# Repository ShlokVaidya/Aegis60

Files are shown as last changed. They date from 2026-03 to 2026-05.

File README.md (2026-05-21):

# Aegis60
Aegis60 is my custom 60% mechanical keyboard project built around an RP2040-ZERO controller.
<p>
I wanted a keyboard that felt clean and simple like a classic 60%, but still let me fully understand how the electronics actually work (matrix, diodes, routing, and firmware pin mapping), not just buy a kit and screw it together.
</p>
<br>


<br>
## Why I made this

I am 17 and I use my keyboard for school every day, so I wanted to build one that is actually mine from scratch.

Main goals I set for myself:
- Design a full 60% PCB in KiCad (61 keys)
- Use hot-swap MX footprints so it is easy to test switches
- Keep the design manufacturable and not just a concept render
- Learn the full pipeline: schematic -> PCB -> 3D model -> production files

## Project status

This repo includes the complete hardware design files and manufacturing outputs:
- KiCad project, schematic, and PCB
- 3D CAD export (.step)
- Plate DXF
- Production files (BOM, positions, designators, netlist)
- Custom RP2040-ZERO symbol/footprint library files

Current hardware summary:
- Layout: 60% ANSI style, 61 keys
- Controller: RP2040-ZERO
- Matrix: diode matrix (1 diode per switch)
- Stabilizers: 2u, 2.25u, 2.75u, 6.25u support

## Images

### Full 3D model screenshot

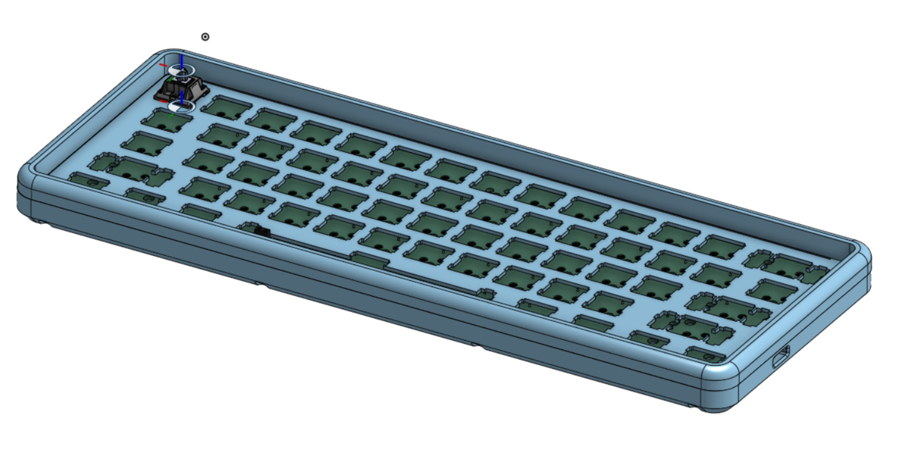
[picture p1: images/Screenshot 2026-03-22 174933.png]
Aegis60 full 3D model


### PCB screenshot

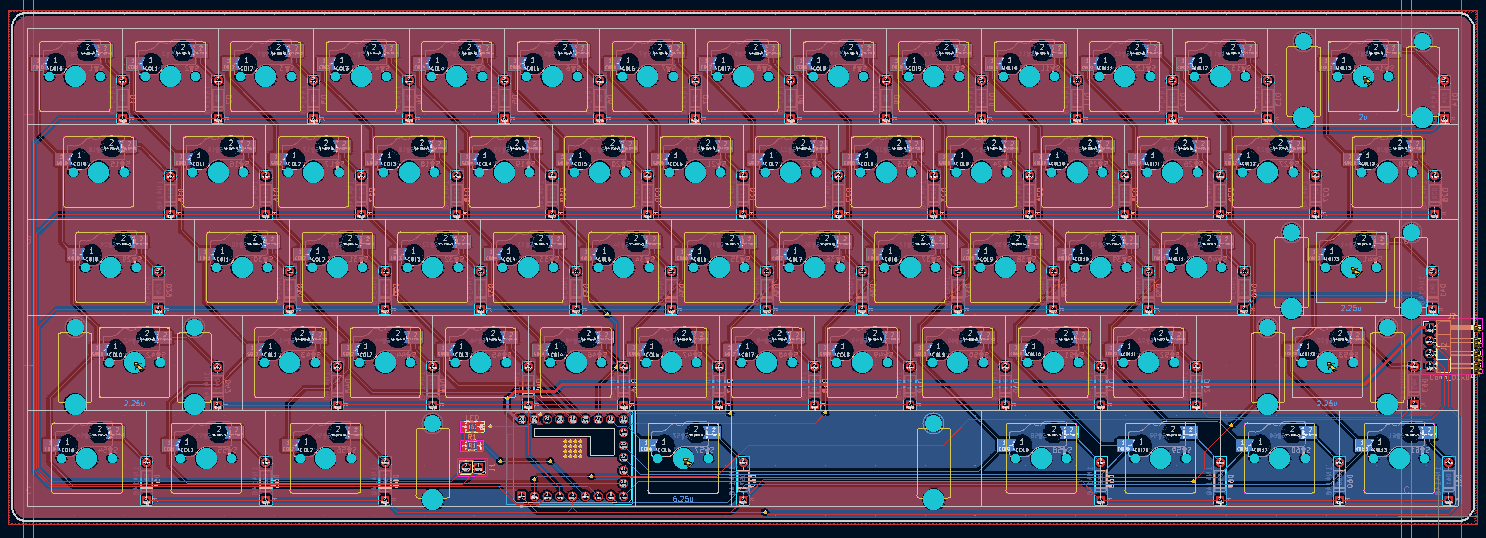
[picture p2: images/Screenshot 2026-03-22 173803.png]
Aegis60 PCB routing


### Wiring / schematic screenshot

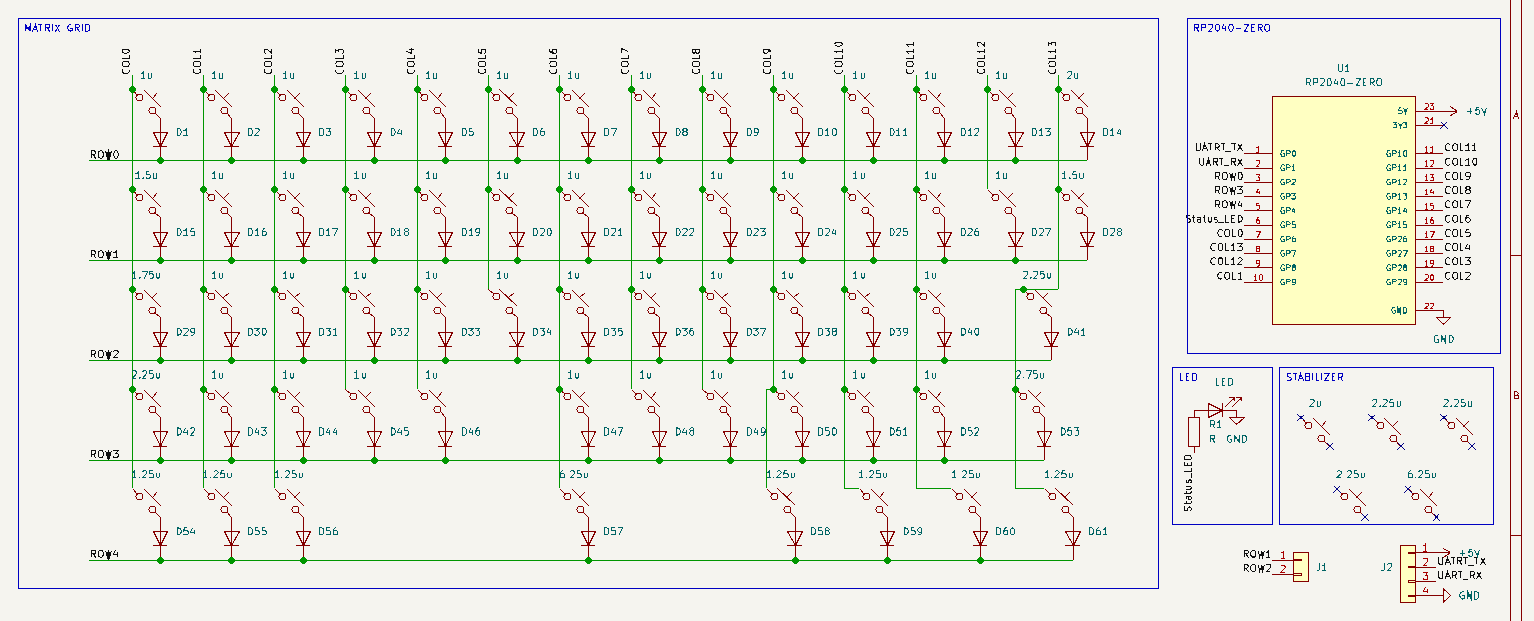
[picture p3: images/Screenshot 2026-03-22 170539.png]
Aegis60 schematic matrix and RP2040 pinout


### Other Screenshots













### Build







## Repo file checklist

Important files in this repository:
- `Aegis60.kicad_pro`
- `Aegis60.kicad_sch`
- `Aegis60.kicad_pcb`
- `Aegis60.step`
- `Plate.dxf`
- `bom.csv`
- `production/bom.csv`
- `production/positions.csv`
- `production/designators.csv`
- `production/netlist.ipc`

## CAD

OnShape: [link](https://cad.onshape.com/documents/3631dcb843d220359551c32b/w/64ccd39e08fb4eede3b1f39f/e/fad0ee0c4f93314d35213121)

## Firmware note

A KMK starter firmware is included in this repo:

- `firmware/kmk/main.py`
- `firmware/kmk/README.md`

It includes the row/column pin mapping from the current netlist and a base ANSI-like 61-key layout.

## BOM (summary)

Current BOM is in `bom.csv`.

| Name | Purpose | Quantity | Total Cost (USD) | Distributor | Link |
|---|---|---:|---:|---|---|
| 3D printed Case | 3D printing | 1 | 8.19 | Hack Club | https://printlegion.hackclub.com |
| PCB fabrication | PCB | 1 | 39.20 | Robu.in | https://robu.in/product/online-pcb-manufacturing-service/ |
| RP2040-zero | Microcontroller | 1 | 6.05 | Robu.in | https://robu.in/product/waveshare-rp2040-zero-raspberry-pi-mcu-with-presoldered-header/ |
| Cherry PBT Keycaps | Keycaps | 1 | 17.47 | Curiosity Caps | https://curiositycaps.in/products/counter-strike-printstream-decal-collectio-n-cherry-pbt-keycaps |
| Durock Smokey Screw-In Stabilizers V2 | Stabilizers | 1 | 17.00 | StacksKB | https://stackskb.com/store/durock-smokey-screw-in-stabilizers-v2/ |
| Akko V5 Creamy Blue Pro Switch (Pack of 45) | For typing I guess ? | 1 | 13.14 | StacksKB | https://stackskb.com/store/akko-v5-creamy-blue-pro-switch-pack-of-45/ |

**Total BOM cost:** 101.05 USD

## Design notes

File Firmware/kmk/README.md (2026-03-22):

# Aegis60 KMK Firmware

This is a starter KMK firmware for the Aegis60 (RP2040-ZERO).

## What this includes
- Exact row/column GPIO mapping from the current hardware netlist
- 61-key ANSI-like base layer
- Sparse matrix handling with `KC.NO` for physically empty matrix slots

## Flash steps
1. Install CircuitPython on RP2040-ZERO (if not already installed).
2. Copy the KMK library folder to your `CIRCUITPY` drive.
3. Copy `main.py` from this folder to the root of `CIRCUITPY`.
4. Replug/reset the board.

## Notes
- Matrix diode direction is configured as `COL2ROW`.
- In the schematic/netlist, GP0/GP1 are named `UATRT_TX` / `UART_RX` but are used as matrix rows in this design.
- If any key appears in the wrong place, verify switch orientation and matrix continuity first, then tune keycodes in `main.py`.

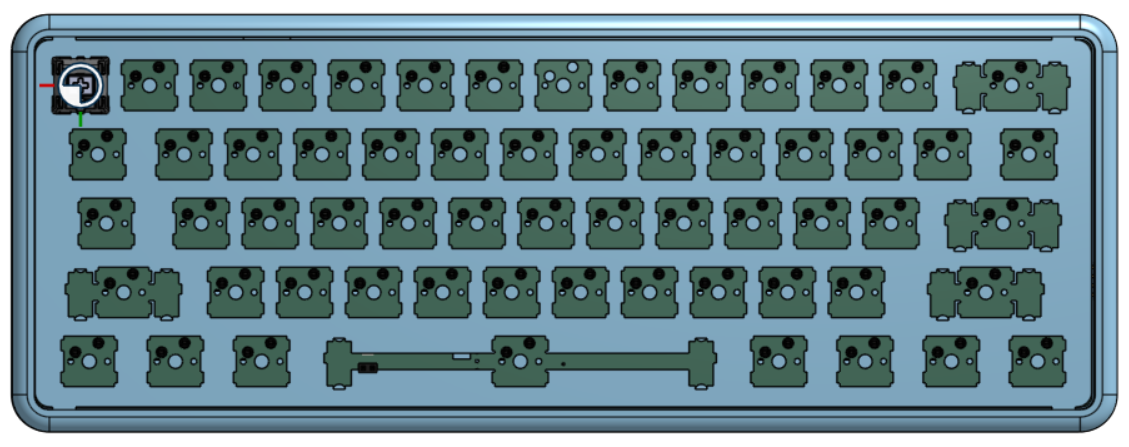
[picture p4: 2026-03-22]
images/Screenshot 2026-03-22 175005.png

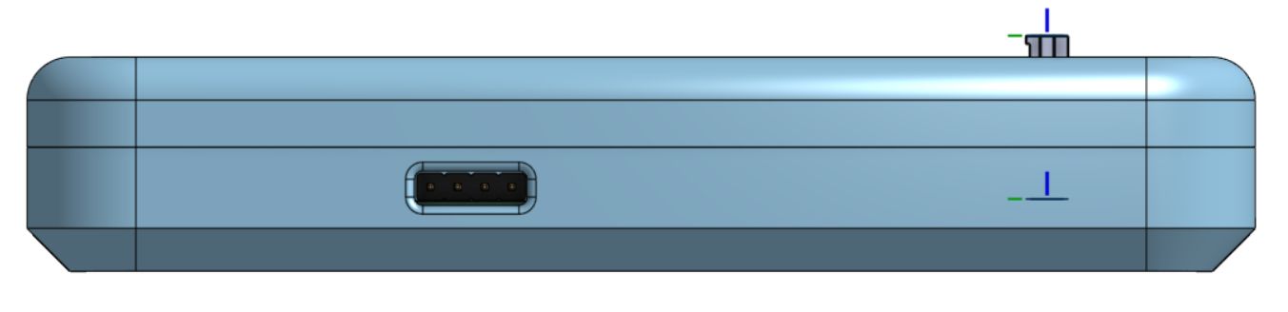
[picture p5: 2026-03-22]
images/Screenshot 2026-03-22 175134.png

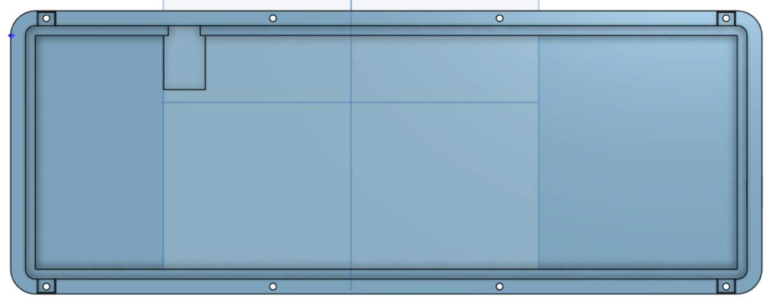
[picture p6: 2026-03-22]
images/Screenshot 2026-03-22 175245.png

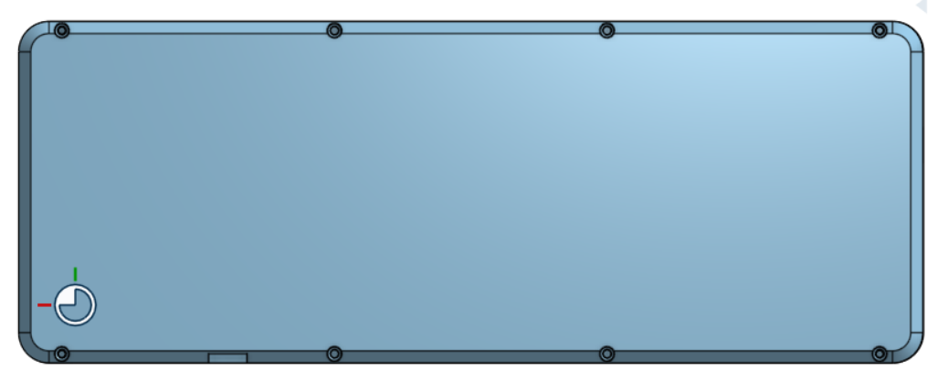
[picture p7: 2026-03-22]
images/Screenshot 2026-03-22 175213.png

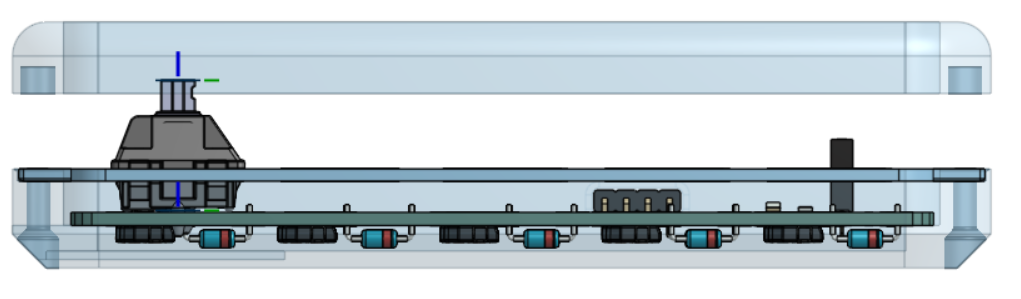
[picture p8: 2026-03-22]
images/Screenshot 2026-03-22 175058.png

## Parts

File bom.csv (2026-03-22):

Name | Purpose | Quantity | Total Cost (USD) | Link | Distributor
3D printed Case | 3D printing | 1 | 8.19 | https://printlegion.hackclub.com | Hack Club
PCB fabrication | PCB | 1 | 39.20 | https://robu.in/product/online-pcb-manufacturing-service/ | Robu.in
RP2040-zero | Microcontroller | 1 | 6.05 | https://robu.in/product/waveshare-rp2040-zero-raspberry-pi-mcu-with-presoldered-header/ | Robu.in
Cherry PBT Keycaps | Keycaps | 1 | 17.47 | https://curiositycaps.in/products/counter-strike-printstream-decal-collectio-n-cherry-pbt-keycaps | Curiosity Caps
Durock Smokey Screw-In Stabilizers V2 | Stabilizers | 1 | 17.00 | https://stackskb.com/store/durock-smokey-screw-in-stabilizers-v2/ | StacksKB
Akko V5 Creamy Blue Pro Switch (Pack of 45) | For typing I guess ? | 1 | 13.14 | https://stackskb.com/store/akko-v5-creamy-blue-pro-switch-pack-of-45/ | StacksKB

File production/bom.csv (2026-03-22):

Designator | Footprint | Quantity | Value | LCSC Part #
D1, D10, D11, D12, D13, D14, D15, D16, D17, D18, D19, D2, D20, D21, D22, D23, D24, D25, D26, D27, D28, D29, D3, D30, D31, D32, D33, D34, D35, D36, D37, D38, D39, D4, D40, D41, D42, D43, D44, D45, D46, D47, D48, D49, D5, D50, D51, D52, D53, D54, D55, D56, D57, D58, D59, D6, D60, D61, D7, D8, D9 | D_DO-35_SOD27_P7.62mm_Horizontal | 61 | 1N4148
D62 | 1206 | 1 | LED
J1 | PinSocket_1x02_P2.54mm_Vertical | 1 | Conn_01x02
J2 | PinHeader_1x04_P2.54mm_Horizontal | 1 | Conn_01x04
R1 | 1206 | 1 | R
STAB1 | STAB_MX_2u | 1 | 2u
STAB2, STAB3 | STAB_MX_2.25u | 2 | 2.25u
STAB4 | STAB_MX_2.75u | 1 | 2.25u
STAB5 | STAB_MX_6.25u | 1 | 6.25u
SW1, SW10, SW11, SW12, SW13, SW16, SW17, SW18, SW19, SW2, SW20, SW21, SW22, SW23, SW24, SW25, SW26, SW27, SW3, SW30, SW31, SW32, SW33, SW34, SW35, SW36, SW37, SW38, SW39, SW4, SW40, SW43, SW44, SW45, SW46, SW47, SW48, SW49, SW5, SW50, SW51, SW52, SW6, SW7, SW8, SW9 | SW_MX_HS_KS-2P02B01-01_1u | 46 | 1u
SW14 | SW_MX_HS_KS-2P02B01-01_1u | 1 | 2u
SW15, SW28 | SW_MX_HS_KS-2P02B01-01_1.5u | 2 | 1.5u
SW29 | SW_MX_HS_KS-2P02B01-01_1.75u | 1 | 1.75u
SW41, SW42 | SW_MX_HS_KS-2P02B01-01_1u | 2 | 2.25u
SW53 | SW_MX_HS_KS-2P02B01-01_1u | 1 | 2.75u
SW54, SW55, SW56, SW58, SW59, SW60, SW61 | SW_MX_HS_KS-2P02B01-01_1.25u | 7 | 1.25u
SW57 | SW_MX_HS_KS-2P02B01-01_1u | 1 | 6.25u
U1 | MODULE_RP2040-ZERO | 1 | RP2040-ZERO

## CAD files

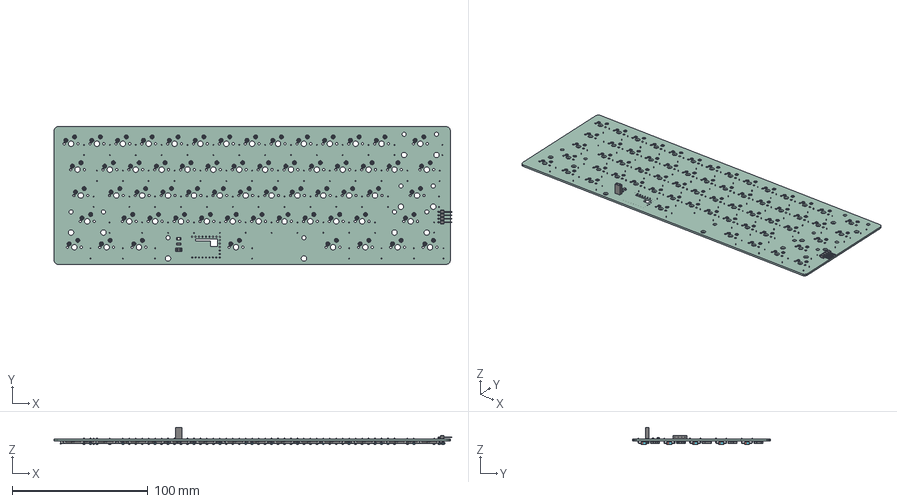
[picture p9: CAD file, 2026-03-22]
Aegis60.step
293.1 x 101.4 x 12.7 mm
PinSocket_1x02_P2.54mm_Vertical
R_1206_3216Metric
LED_1206_3216Metric
PinHeader_1x04_P2.54mm_Horizontal
HS_KS-2P02B01-01_MX x 61
D_DO-35_SOD27_P7.62mm_Horizontal x 61
Aegis60_PCB

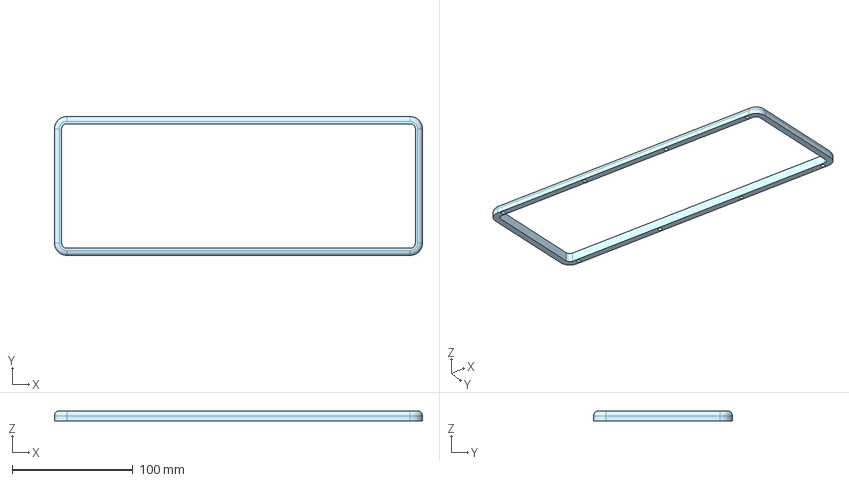
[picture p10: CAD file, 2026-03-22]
CAD/Cover.step
305.0 x 115.0 x 8.40 mm

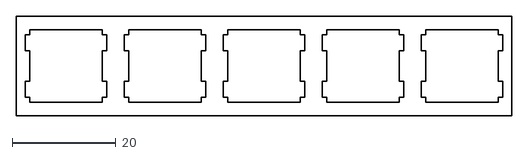
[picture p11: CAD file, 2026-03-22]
PCB/Plate.dxf
95.3 x 19.1

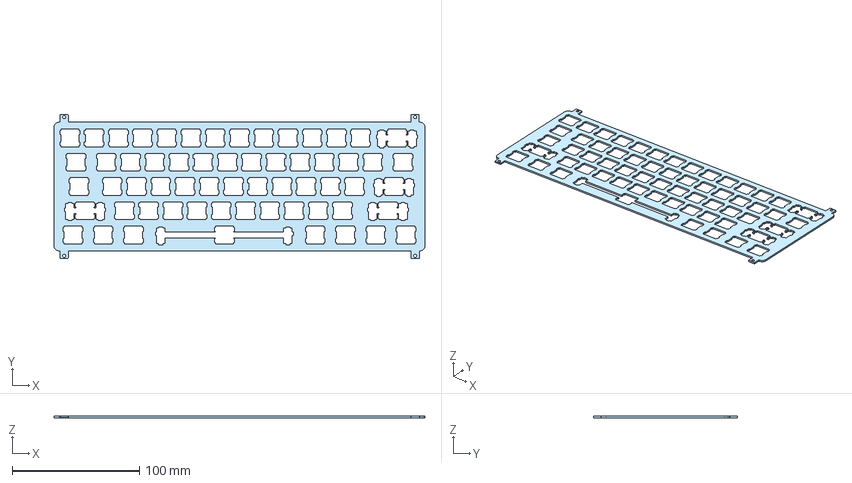
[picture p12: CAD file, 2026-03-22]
CAD/Plate.step
291.7 x 113.4 x 1.40 mm

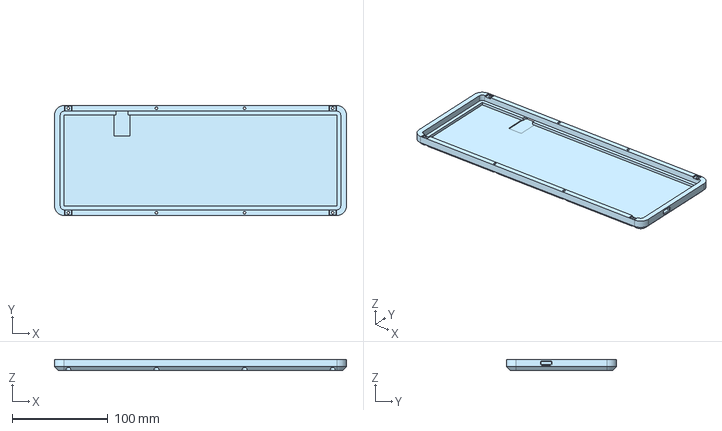
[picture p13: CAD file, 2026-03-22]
CAD/Bottom_Case.step
305.0 x 115.0 x 11.6 mm

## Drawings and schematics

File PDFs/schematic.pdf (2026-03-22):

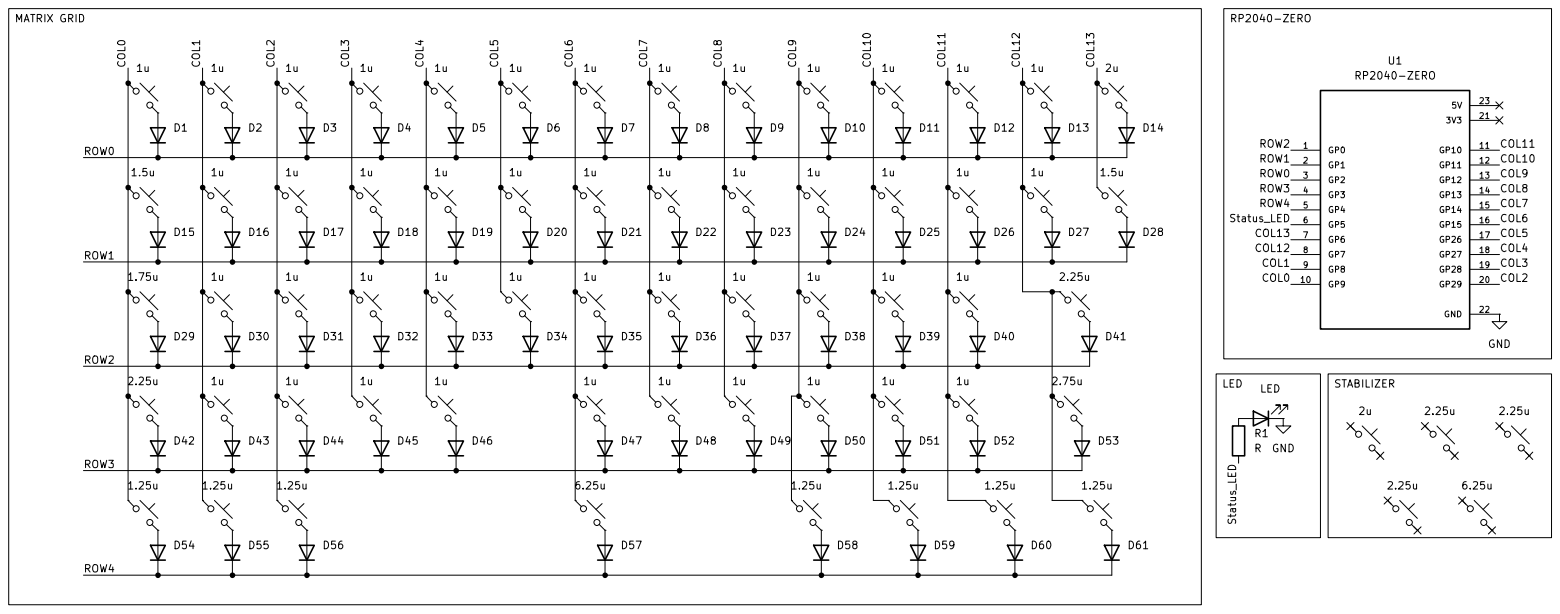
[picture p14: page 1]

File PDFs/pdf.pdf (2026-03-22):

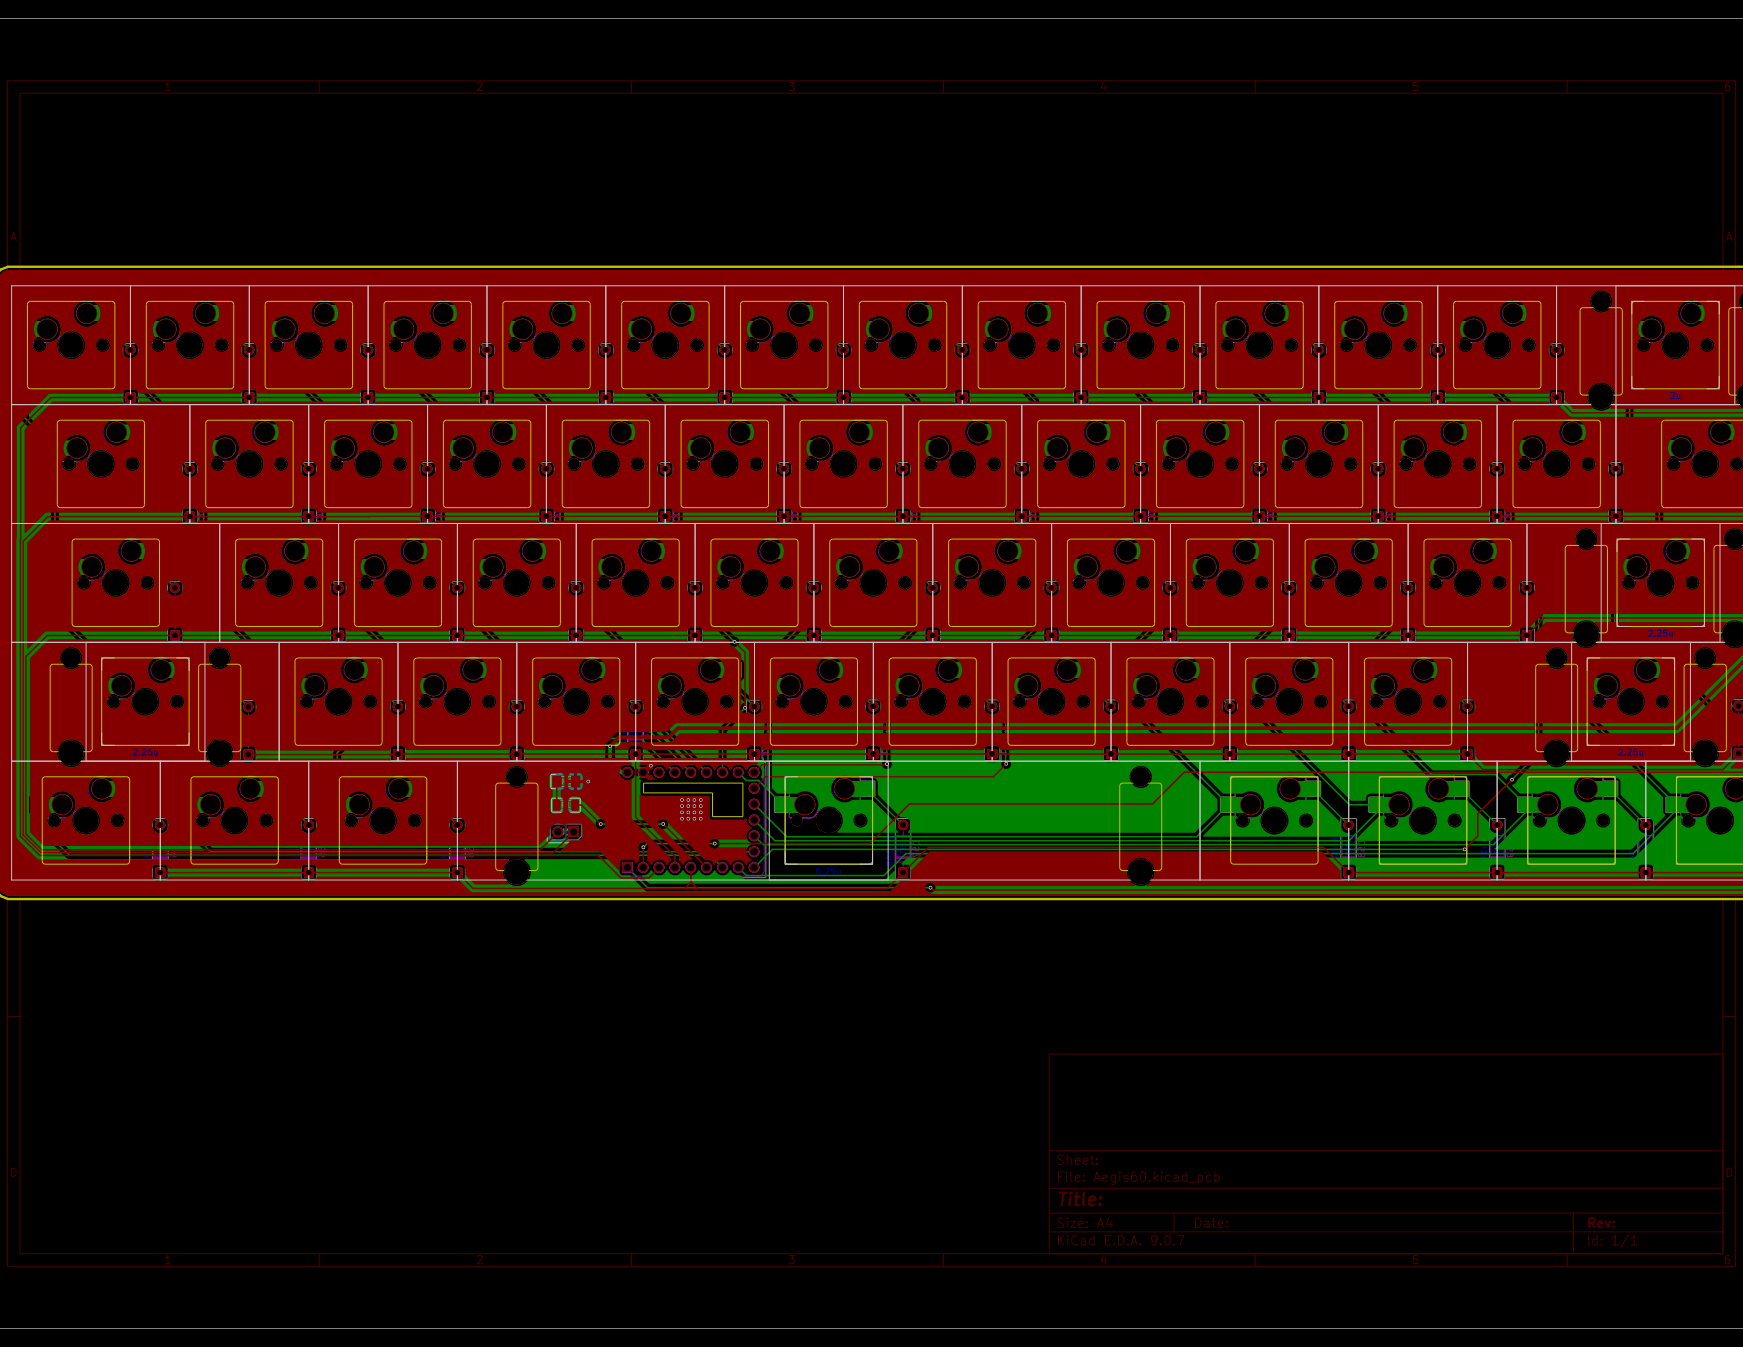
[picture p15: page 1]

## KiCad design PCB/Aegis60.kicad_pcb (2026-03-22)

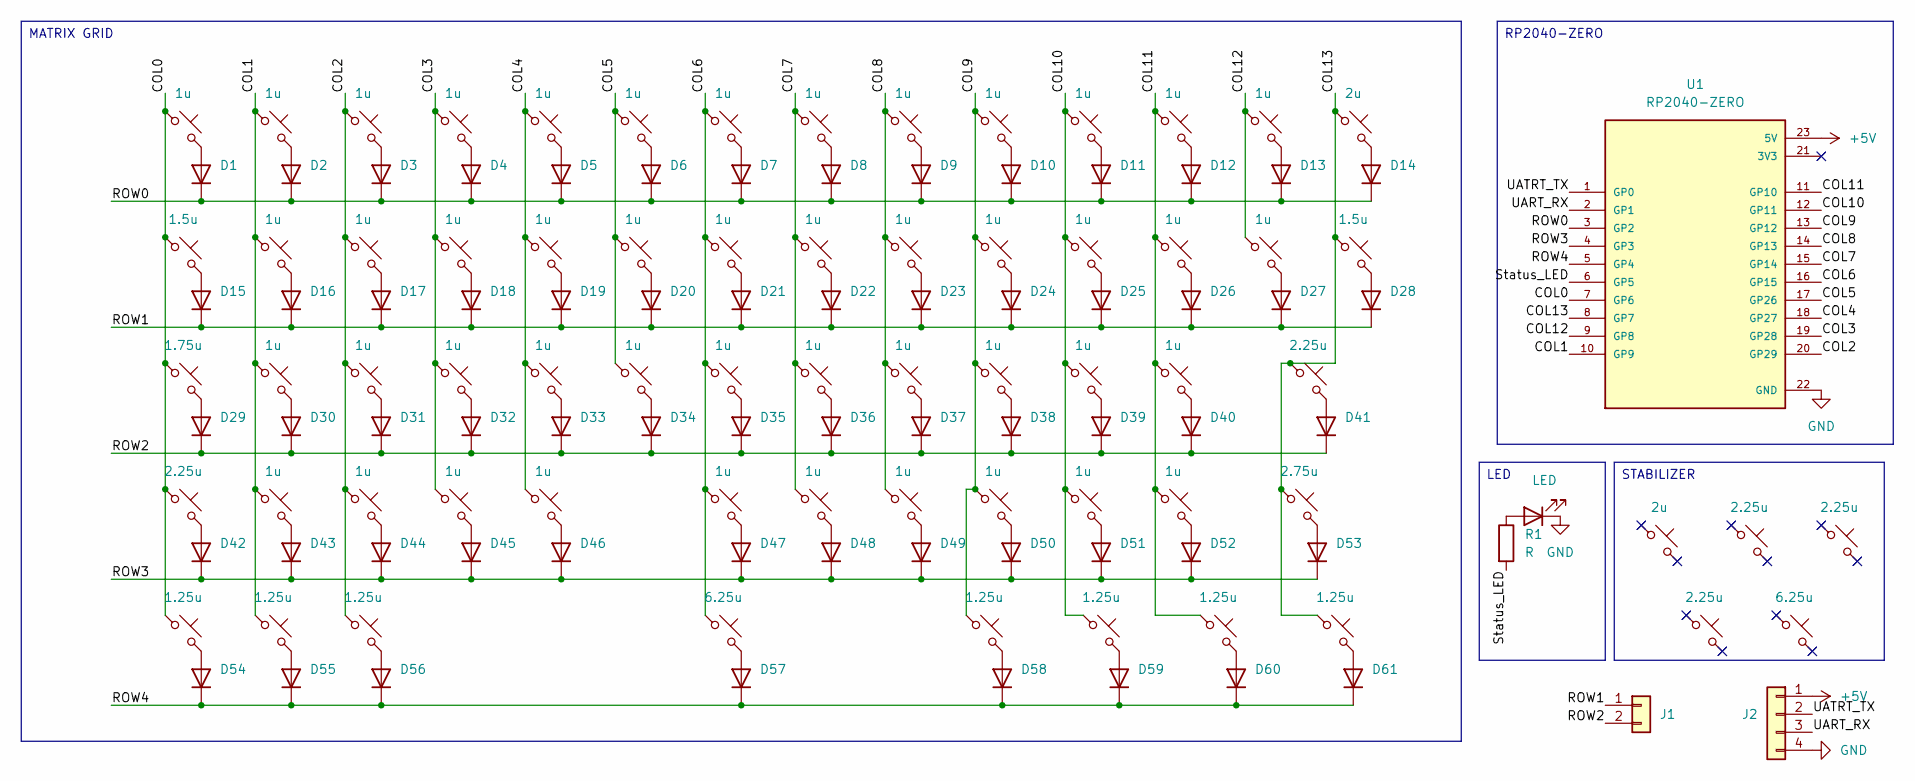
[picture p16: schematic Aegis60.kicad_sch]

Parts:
D1, D2, D3, D4, D5, D6, D7, D8, D9, D10, D11, D12, D13, D14, D15, D16, D17, D18, D19, D20, D21, D22, D23, D24, D25, D26, D27, D28, D29, D30, D31, D32, D33, D34, D35, D36, D37, D38, D39, D40, D41, D42, D43, D44, D45, D46, D47, D48, D49, D50, D51, D52, D53, D54, D55, D56, D57, D58, D59, D60, D61: 1N4148; D_DO-35_SOD27_P7.62mm_Horizontal
D62: LED; LED_1206_3216Metric_Pad1.42x1.75mm_HandSolder
J1: Conn_01x02; PinSocket_1x02_P2.54mm_Vertical
J2: Conn_01x04; PinHeader_1x04_P2.54mm_Horizontal
R1: R; R_1206_3216Metric
STAB1: 2u; STAB_MX_2u
STAB2, STAB3: 2.25u; STAB_MX_2.25u
STAB4: 2.25u; STAB_MX_2.75u
STAB5: 6.25u; STAB_MX_6.25u
SW1, SW2, SW3, SW4, SW5, SW6, SW7, SW8, SW9, SW10, SW11, SW12, SW13, SW16, SW17, SW18, SW19, SW20, SW21, SW22, SW23, SW24, SW25, SW26, SW27, SW30, SW31, SW32, SW33, SW34, SW35, SW36, SW37, SW38, SW39, SW40, SW43, SW44, SW45, SW46, SW47, SW48, SW49, SW50, SW51, SW52: 1u; SW_MX_HS_KS-2P02B01-01_1u
SW14: 2u; SW_MX_HS_KS-2P02B01-01_1u
SW15, SW28: 1.5u; SW_MX_HS_KS-2P02B01-01_1.5u
SW29: 1.75u; SW_MX_HS_KS-2P02B01-01_1.75u
SW41, SW42: 2.25u; SW_MX_HS_KS-2P02B01-01_1u
SW53: 2.75u; SW_MX_HS_KS-2P02B01-01_1u
SW54, SW55, SW56, SW58, SW59, SW60, SW61: 1.25u; SW_MX_HS_KS-2P02B01-01_1.25u
SW57: 6.25u; SW_MX_HS_KS-2P02B01-01_1u
U1: RP2040-ZERO; MODULE_RP2040-ZERO; PARTREV NA

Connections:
+5V: J2.1, U1.23 (5V)
/COL0: SW1.1, SW15.1, SW29.1, SW42.1, SW54.1, U1.7 (GP6)
/COL1: SW2.1, SW16.1, SW30.1, SW43.1, SW55.1, U1.10 (GP9)
/COL2: SW3.1, SW17.1, SW31.1, SW44.1, SW56.1, U1.20 (GP29)
/COL3: SW4.1, SW18.1, SW32.1, SW45.1, U1.19 (GP28)
/COL4: SW5.1, SW19.1, SW33.1, SW46.1, U1.18 (GP27)
/COL5: SW6.1, SW20.1, SW34.1, U1.17 (GP26)
/COL6: SW7.1, SW21.1, SW35.1, SW47.1, SW57.1, U1.16 (GP15)
/COL7: SW8.1, SW22.1, SW36.1, SW48.1, U1.15 (GP14)
/COL8: SW9.1, SW23.1, SW37.1, SW49.1, U1.14 (GP13)
/COL9: SW10.1, SW24.1, SW38.1, SW50.1, SW58.1, U1.13 (GP12)
/COL10: SW11.1, SW25.1, SW39.1, SW51.1, SW59.1, U1.12 (GP11)
/COL11: SW12.1, SW26.1, SW40.1, SW52.1, SW60.1, U1.11 (GP10)
/COL12: SW13.1, SW27.1, U1.9 (GP8)
/COL13: SW14.1, SW28.1, SW41.1, SW53.1, SW61.1, U1.8 (GP7)
/ROW0: D1.1 (K), D2.1 (K), D3.1 (K), D4.1 (K), D5.1 (K), D6.1 (K), D7.1 (K), D8.1 (K), D9.1 (K), D10.1 (K), D11.1 (K), D12.1 (K), D13.1 (K), D14.1 (K), U1.3 (GP2)
/ROW1: D15.1 (K), D16.1 (K), D17.1 (K), D18.1 (K), D19.1 (K), D20.1 (K), D21.1 (K), D22.1 (K), D23.1 (K), D24.1 (K), D25.1 (K), D26.1 (K), D27.1 (K), D28.1 (K), J1.1
/ROW2: D29.1 (K), D30.1 (K), D31.1 (K), D32.1 (K), D33.1 (K), D34.1 (K), D35.1 (K), D36.1 (K), D37.1 (K), D38.1 (K), D39.1 (K), D40.1 (K), D41.1 (K), J1.2
/ROW3: D42.1 (K), D43.1 (K), D44.1 (K), D45.1 (K), D46.1 (K), D47.1 (K), D48.1 (K), D49.1 (K), D50.1 (K), D51.1 (K), D52.1 (K), D53.1 (K), U1.4 (GP3)
/ROW4: D54.1 (K), D55.1 (K), D56.1 (K), D57.1 (K), D58.1 (K), D59.1 (K), D60.1 (K), D61.1 (K), U1.5 (GP4)
/Status_LED: R1.2, U1.6 (GP5)
/UART_RX: J2.3, U1.2 (GP1)
/UATRT_TX: J2.2, U1.1 (GP0)
GND: D62.1 (K), J2.4, U1.22 (GND)
unnamed: D1.2 (A), SW1.2
unnamed: D2.2 (A), SW2.2
unnamed: D3.2 (A), SW3.2
unnamed: D4.2 (A), SW4.2
unnamed: D5.2 (A), SW5.2
unnamed: D6.2 (A), SW6.2
unnamed: D7.2 (A), SW7.2
unnamed: D8.2 (A), SW8.2
unnamed: D9.2 (A), SW9.2
unnamed: D10.2 (A), SW10.2
unnamed: D11.2 (A), SW11.2
unnamed: D12.2 (A), SW12.2
unnamed: D13.2 (A), SW13.2
unnamed: D14.2 (A), SW14.2
unnamed: D15.2 (A), SW15.2
unnamed: D16.2 (A), SW16.2
unnamed: D17.2 (A), SW17.2
unnamed: D18.2 (A), SW18.2
unnamed: D19.2 (A), SW19.2
unnamed: D20.2 (A), SW20.2
unnamed: D21.2 (A), SW21.2
unnamed: D22.2 (A), SW22.2
unnamed: D23.2 (A), SW23.2
unnamed: D24.2 (A), SW24.2
unnamed: D25.2 (A), SW25.2
unnamed: D26.2 (A), SW26.2
unnamed: D27.2 (A), SW27.2
unnamed: D28.2 (A), SW28.2
unnamed: D29.2 (A), SW29.2
unnamed: D30.2 (A), SW30.2
unnamed: D31.2 (A), SW31.2
unnamed: D32.2 (A), SW32.2
unnamed: D33.2 (A), SW33.2
unnamed: D34.2 (A), SW34.2
unnamed: D35.2 (A), SW35.2
unnamed: D36.2 (A), SW36.2
unnamed: D37.2 (A), SW37.2
unnamed: D38.2 (A), SW38.2
unnamed: D39.2 (A), SW39.2
unnamed: D40.2 (A), SW40.2
unnamed: D41.2 (A), SW41.2
unnamed: D42.2 (A), SW42.2
unnamed: D43.2 (A), SW43.2
unnamed: D44.2 (A), SW44.2
unnamed: D45.2 (A), SW45.2
unnamed: D46.2 (A), SW46.2
unnamed: D47.2 (A), SW47.2
unnamed: D48.2 (A), SW48.2
unnamed: D49.2 (A), SW49.2
unnamed: D50.2 (A), SW50.2
unnamed: D51.2 (A), SW51.2
unnamed: D52.2 (A), SW52.2
unnamed: D53.2 (A), SW53.2
unnamed: D54.2 (A), SW54.2
unnamed: D55.2 (A), SW55.2
unnamed: D56.2 (A), SW56.2
unnamed: D57.2 (A), SW57.2
unnamed: D58.2 (A), SW58.2
unnamed: D59.2 (A), SW59.2
unnamed: D60.2 (A), SW60.2
unnamed: D61.2 (A), SW61.2
unnamed: D62.2 (A), R1.1

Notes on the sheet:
STABILIZER
RP2040-ZERO
LED
MATRIX GRID

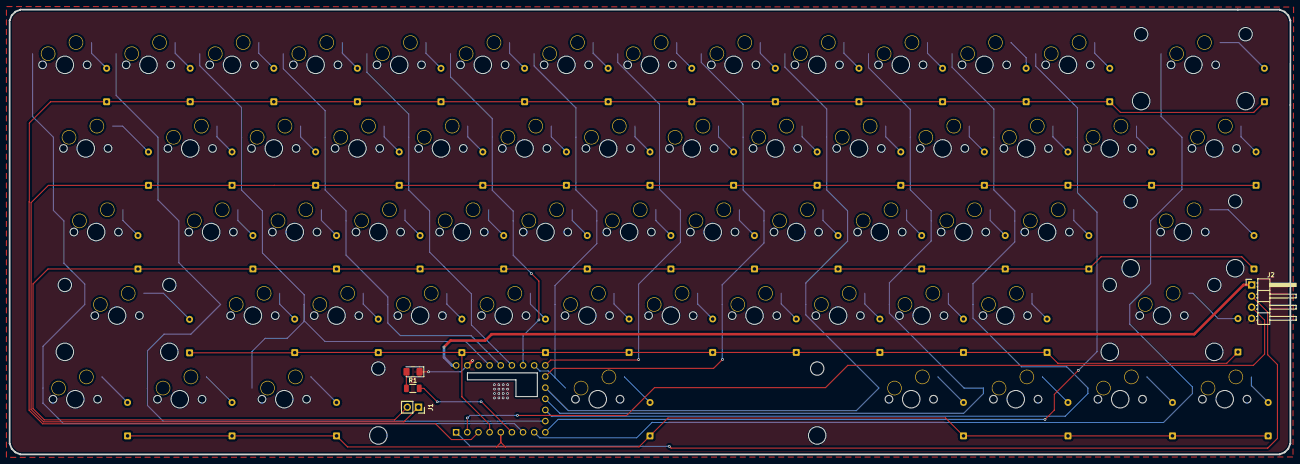
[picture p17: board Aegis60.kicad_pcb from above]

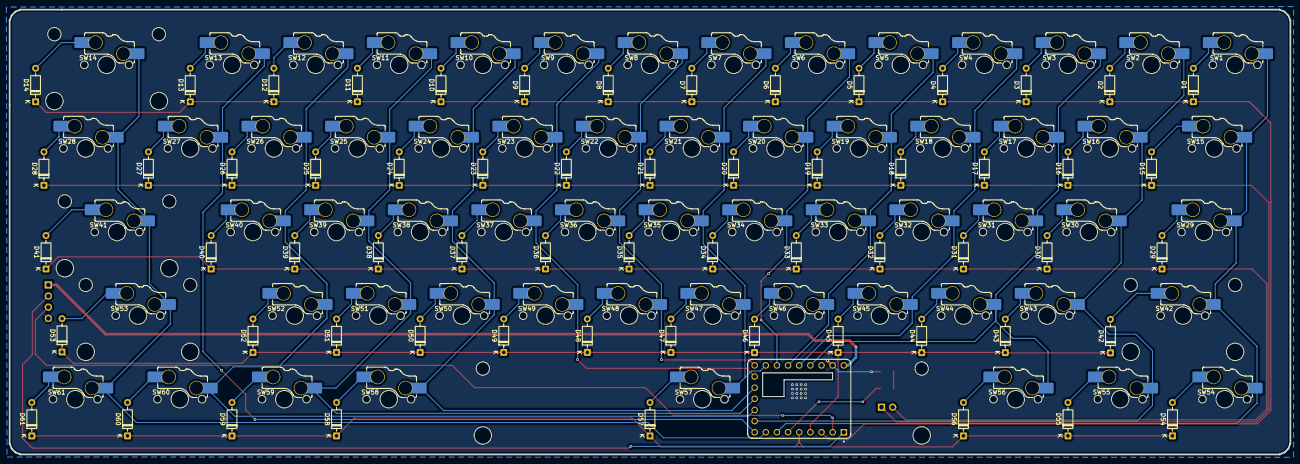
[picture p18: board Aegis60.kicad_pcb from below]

Board: 2 copper layers, 291.9 x 101.4 mm, 132 parts (123 on the bottom side), 86 nets.

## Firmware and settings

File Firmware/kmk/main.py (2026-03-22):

import board
from kmk.kmk_keyboard import KMKKeyboard
from kmk.keys import KC
from kmk.scanners import DiodeOrientation

keyboard = KMKKeyboard()

# RP2040-ZERO pin map from Aegis60 schematic/netlist.
keyboard.col_pins = (
    board.GP6,   # COL0
    board.GP9,   # COL1
    board.GP29,  # COL2
    board.GP28,  # COL3
    board.GP27,  # COL4
    board.GP26,  # COL5
    board.GP15,  # COL6
    board.GP14,  # COL7
    board.GP13,  # COL8
    board.GP12,  # COL9
    board.GP11,  # COL10
    board.GP10,  # COL11
    board.GP8,   # COL12
    board.GP7,   # COL13
)

keyboard.row_pins = (
    board.GP2,  # ROW0
    board.GP0,  # ROW1 (net label UATRT_TX in project files)
    board.GP1,  # ROW2 (net label UART_RX in project files)
    board.GP3,  # ROW3
    board.GP4,  # ROW4
)

keyboard.diode_orientation = DiodeOrientation.COL2ROW

NO = KC.NO

keyboard.keymap = [
    [
        KC.GRV, KC.N1, KC.N2, KC.N3, KC.N4, KC.N5, KC.N6,
        KC.N7, KC.N8, KC.N9, KC.N0, KC.MINS, KC.EQL, KC.BSPC,
    ],
    [
        KC.TAB, KC.Q, KC.W, KC.E, KC.R, KC.T, KC.Y,
        KC.U, KC.I, KC.O, KC.P, KC.LBRC, KC.RBRC, KC.BSLS,
    ],
    [
        KC.CAPS, KC.A, KC.S, KC.D, KC.F, KC.G, KC.H,
        KC.J, KC.K, KC.L, KC.SCLN, KC.QUOT, NO, KC.ENT,
    ],
    [
        KC.LSFT, KC.Z, KC.X, KC.C, KC.V, NO, KC.B,
        KC.N, KC.M, KC.COMM, KC.DOT, KC.SLSH, NO, KC.RSFT,
    ],
    [
        KC.LCTL, KC.LGUI, KC.LALT, NO, NO, NO, KC.SPC,
        NO, NO, KC.RALT, KC.RGUI, KC.APP, NO, KC.RCTL,
    ],
]

if __name__ == '__main__':
    keyboard.go()

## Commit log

2026-03-22 revised v2.2
    [Aegis60.kicad_pcb, Aegis60.kicad_sch, Aegis60.step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]
2026-03-22 revised v2.3
    [Bottom_Case.step, Cover.step, Plate.step]
2026-03-22 revised v2.4
    [Aegis60.kicad_pcb, Aegis60.kicad_sch, Bottom_Case.step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]
